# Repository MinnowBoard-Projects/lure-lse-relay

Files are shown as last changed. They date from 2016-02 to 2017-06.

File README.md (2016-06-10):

# lure-lse-relay  
"Relay Lure" for MinnowBoard MAX / Turbot compatible boards Low Speed Expansion (LSE) header  

Features
4-channel Relay Lure that can handle ~6A, 110VAC / ~4A, 30VDC per channel(Take appropriate precautions when handling this board).  
Screw in Block terminals with Normally Closed and Normally open connections(5mm Pitch).   
GPIOs are protected using Optocouplers.    
Experimental header to connect an HC-06 type Bluetooth module to a UART port, to enable the control of the MinnowBoard with another Bluetooth enabled devices. 

---------------------------------------------

"Big Relay Lure" for MinnowBoard MAX / Turbot compatible boards Low Speed Expansion (LSE) header 

Features
8-channel Relay Lure that can handle ~6A, 110VAC / ~4A, 30VDC per channel(Take appropriate precautions when handling this board).  
Screw in Block terminals with Normally Closed and Normally open connections(9.52mm Pitch).   
GPIOs are protected using Optocouplers. 
1-Wire devices hub, devices can be hooked up via RJ11 connectors and/or screw in block terminals.
The "Big Relay Lure" is an external Lure with 4 holes(2.5mm diameter) for standoffs, connects to the MinnowBoard via a Ribbon Cable.  

Both Designs made in Diptrace 3.0

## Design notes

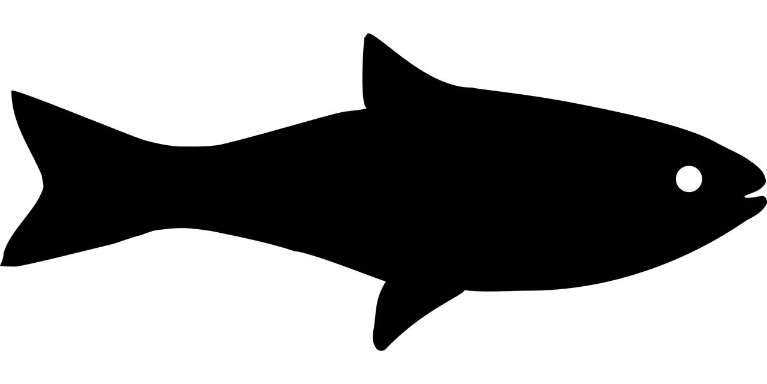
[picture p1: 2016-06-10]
Big Relay Board/Design Files/fish-1294822_1280.tiff

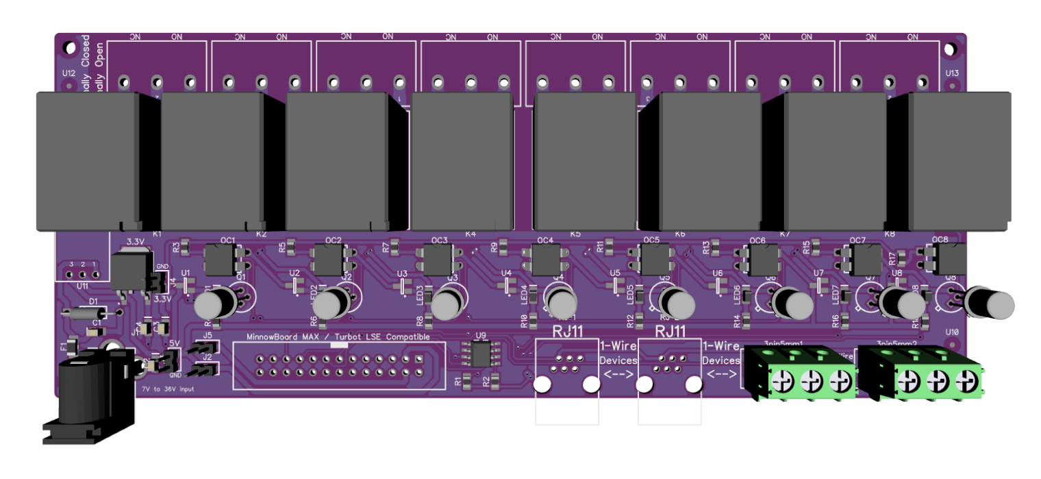
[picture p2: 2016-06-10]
Big Relay Board/Big Relay Lure front.png

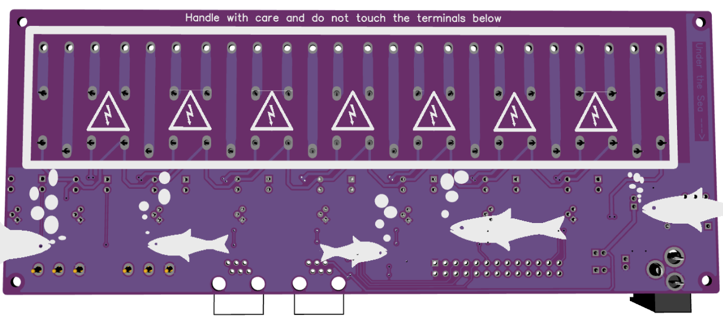
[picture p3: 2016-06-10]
Big Relay Board/Big Relay Lure back.png

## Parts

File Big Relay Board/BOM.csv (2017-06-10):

RefDes | Value | Name | Pattern | Manufacturer | Quantity | Datasheet
3.3V | 3.3V | BA033CC0FP-E2 | TO252-3(4)/10x6.6x2.28 | ROHM | 1
3pin5mm1 | BT1 | 1935174 | 3pin5mm | Phoenix Contact | 1
3pin5mm2 | BT2 | 1935174 | 3pin5mm | Phoenix Contact | 1
3pin6.35mm1 |  | 1714968 | 3pin6.35mm | Phoenix Contact | 1
3pin6.35mm2 |  | 1714968 | 3pin6.35mm | Phoenix Contact | 1
3pin6.35mm3 |  | 1714968 | 3pin6.35mm | Phoenix Contact | 1
3pin6.35mm4 |  | 1714968 | 3pin6.35mm | Phoenix Contact | 1
3pin6.35mm5 |  | 1714968 | 3pin6.35mm | Phoenix Contact | 1
3pin6.35mm6 |  | 1714968 | 3pin6.35mm | Phoenix Contact | 1
3pin6.35mm7 |  | 1714968 | 3pin6.35mm | Phoenix Contact | 1
3pin6.35mm8 |  | 1714968 | 3pin6.35mm | Phoenix Contact | 1
F1 |  | FUSE F1206A2R00FWTR\500 | RES_1206 | AVX | 1
J1 |  | PJ-002AH | PJ-002A | CUI | 1
J2 |  | 87758-02 | HDR-2x1T/2x2/2x4 | Molex | 1
J3 |  | 87758-02 | HDR-2x1T/2x2/2x4 | Molex | 1
J4 |  | 87758-02 | HDR-2x1T/2x2/2x4 | Molex | 1
J5 |  | 87758-02 | HDR-2x1T/2x2/2x4 | Molex | 1
K1 |  | G5LE-14-DC5 | G5LE | Omron | 1
K2 |  | G5LE-14-DC5 | G5LE | Omron | 1
K3 |  | G5LE-14-DC5 | G5LE | Omron | 1
K4 |  | G5LE-14-DC5 | G5LE | Omron | 1
K5 |  | G5LE-14-DC5 | G5LE | Omron | 1
K6 |  | G5LE-14-DC5 | G5LE | Omron | 1
K7 |  | G5LE-14-DC5 | G5LE | Omron | 1
K8 |  | G5LE-14-DC5 | G5LE | Omron | 1
OC1 |  | VO617A | DIP-4 | Vishay Semiconductors | 1 | http://www.vishay.com/doc?83666
OC2 |  | VO617A | DIP-4 | Vishay Semiconductors | 1 | http://www.vishay.com/doc?83666
OC3 |  | VO617A | DIP-4 | Vishay Semiconductors | 1 | http://www.vishay.com/doc?83666
OC4 |  | VO617A | DIP-4 | Vishay Semiconductors | 1 | http://www.vishay.com/doc?83666
OC5 |  | VO617A | DIP-4 | Vishay Semiconductors | 1 | http://www.vishay.com/doc?83666
OC6 |  | VO617A | DIP-4 | Vishay Semiconductors | 1 | http://www.vishay.com/doc?83666
OC7 |  | VO617A | DIP-4 | Vishay Semiconductors | 1 | http://www.vishay.com/doc?83666
OC8 |  | VO617A | DIP-4 | Vishay Semiconductors | 1 | http://www.vishay.com/doc?83666
RJ-1 |  | RJE01-660-01 | RJE01-660-01 | Amphenol | 1
RJ-2 |  | RJE01-660-01 | RJE01-660-01 | Amphenol | 1
ShroudedHeader |  | 61202621621 | Copy_of_shroudedheader26 | Wurth Electronics | 1
U1 |  | MMBD4148 | MMBD4148 | Fairchild | 1
U2 |  | MMBD4148 | MMBD4148 | Fairchild | 1
U3 |  | MMBD4148 | MMBD4148 | Fairchild | 1
U4 |  | MMBD4148 | MMBD4148 | Fairchild | 1
U5 |  | MMBD4148 | MMBD4148 | Fairchild | 1
U6 |  | MMBD4148 | MMBD4148 | Fairchild | 1
U7 |  | MMBD4148 | MMBD4148 | Fairchild | 1
U8 |  | MMBD4148 | MMBD4148 | Fairchild | 1
U9 |  | DS2482S-100 | SOIC-8/150mil | Maxim | 1 | http://datasheets.maxim-ic.com/en/ds/DS2482-100.pdf
U11 |  | OKI-78SR-5/1.5-W36H-C | OKI-78SR-5/1.5-W36H-C | Murata | 1
C1 | 4.7uF | CAP_0805 | CAP_0805 |  | 1
C2 | 4.7uF | CAP_0805 | CAP_0805 |  | 1
C3 | 0.1uF | CAP_0805 | CAP_0805 |  | 1
C4 | 4.7uF | CAP_0805 | CAP_0805 |  | 1
D1 | 1N4001 | DIODE | DO-35 |  | 1
LED1 |  | DIODE_0805 | DIO_0805 |  | 1
LED2 |  | DIODE_0805 | DIO_0805 |  | 1
LED3 |  | DIODE_0805 | DIO_0805 |  | 1
LED4 |  | DIODE_0805 | DIO_0805 |  | 1
LED5 |  | DIODE_0805 | DIO_0805 |  | 1
LED6 |  | DIODE_0805 | DIO_0805 |  | 1
LED7 |  | DIODE_0805 | DIO_0805 |  | 1
LED8 |  | DIODE_0805 | DIO_0805 |  | 1
Q1 |  | 2N2222 | TO-18 |  | 1
Q2 |  | 2N2222 | TO-18 |  | 1
Q3 |  | 2N2222 | TO-18 |  | 1
Q4 |  | 2N2222 | TO-18 |  | 1
Q5 |  | 2N2222 | TO-18 |  | 1
Q6 |  | 2N2222 | TO-18 |  | 1
Q7 |  | 2N2222 | TO-18 |  | 1
Q8 |  | 2N2222 | TO-18 |  | 1
R1 | Rup | RES_0805 | RES_0805 |  | 1
R2 | Rup | RES_0805 | RES_0805 |  | 1
R3 | 390 | RES_0805 | RES_0805 |  | 1
R4 | 180 | RES_0805 | RES_0805 |  | 1
R5 | 390 | RES_0805 | RES_0805 |  | 1
R6 | 180 | RES_0805 | RES_0805 |  | 1
R7 | 390 | RES_0805 | RES_0805 |  | 1
R8 | 180 | RES_0805 | RES_0805 |  | 1
R9 | 390 | RES_0805 | RES_0805 |  | 1
R10 | 180 | RES_0805 | RES_0805 |  | 1
R11 | 390 | RES_0805 | RES_0805 |  | 1
R12 | 180 | RES_0805 | RES_0805 |  | 1
R13 | 390 | RES_0805 | RES_0805 |  | 1
R14 | 180 | RES_0805 | RES_0805 |  | 1
R15 | 390 | RES_0805 | RES_0805 |  | 1
R16 | 180 | RES_0805 | RES_0805 |  | 1
R17 | 390 | RES_0805 | RES_0805 |  | 1
R18 | 180 | RES_0805 | RES_0805 |  | 1

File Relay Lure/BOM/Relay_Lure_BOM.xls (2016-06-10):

MinnowBoard MAX/Turbot Relay Lure
Mouser # | Mfr. # | Manufacturer | Desc. | RoHS | Lifecycle | Customer Part # | Order Qty. | Price (USD) | Ext.: (USD) | Direct Link
651-1935174 | 1935174 | Phoenix Contact | Fixed Terminal Blocks PT 1.5/3-5.0-H | RoHS Compliant |  |  | 4 | $0.52 | $2.08 | http://www.mouser.com/Search/ProductDetail.aspx?R=1935174virtualkey65100000virtualkey651-1935174
653-G5LE-14-DC5 | G5LE-14-DC5 | Omron | General Purpose Relays Power PCB Relay SPDT Sealed 5VDC | RoHS Compliant |  |  | 4 | $1.35 | $5.40 | http://www.mouser.com/Search/ProductDetail.aspx
610-2N2222 | 2N2222 | Central Semiconductor | Bipolar Transistors - BJT NPN Silicon | RoHS Compliant |  |  | 4 | $1.79 | $7.16 | http://www.mouser.com/Search/ProductDetail.aspx?R=2N2222virtualkey61000000virtualkey610-2N2222
855-M20-7831346 | M20-7831346 | Harwin | Headers & Wire Housings 13+13 DIL VERTICAL SOCKET TIN | RoHS Compliant |  |  | 1 | $2.36 | $2.36 | http://www.mouser.com/Search/ProductDetail.aspx
512-MMBD4148 | MMBD4148 | Fairchild Semiconductor | Diodes - General Purpose, Power, Switching High Cond Ult Fst Di | RoHS Compliant |  |  | 4 | $0.17 | $0.68 | http://www.mouser.com/Search/ProductDetail.aspx?R=MMBD4148virtualkey51210000virtualkey512-MMBD4148
652-CR0805JW-391ELF | CR0805-JW-391ELF | Bourns | Thick Film Resistors - SMD 390ohm 5% | RoHS Compliant By Exemption |  |  | 4 | $0.10 | $0.40 | http://www.mouser.com/Search/ProductDetail.aspx
78-VO617A | VO617A | Vishay | Transistor Output Optocouplers Phototransistor Out CTR 50-600% | RoHS Compliant |  |  | 4 | $0.60 | $2.40 | http://www.mouser.com/Search/ProductDetail.aspx?R=VO617Avirtualkey61370000virtualkey78-VO617A
667-ERJ-6GEYJ181V | ERJ-6GEYJ181V | Panasonic | Thick Film Resistors - SMD 0805 180ohms 5% Tol | RoHS Compliant By Exemption |  |  | 4 | $0.09 | $0.36 | http://www.mouser.com/Search/ProductDetail.aspx
696-SML-LXT0805IW | SML-LXT0805IW-TR | Lumex | Standard LEDs - SMD 0805 Thin PCB Red | RoHS Compliant |  |  | 4 | $0.35 | $1.40 | http://www.mouser.com/Search/ProductDetail.aspx

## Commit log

2016-02-20 Update README.md
    Relay Lure Features
2016-02-20 Update README.md
    Ampere handling in when using DC voltages, and message to take appropriate precautions when handling this board.
2016-02-27 Update to Rev 1.01
    Rev 1.01 includes minor fixes in the PCB layout from which new Gerber
    files were generated to reflect this changes.
    [BoardOutline.gbr, Bottom.gbr, BottomDimension.gbr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]
2016-03-10 Part rename
    Renamed the header part to “MAX / Turbot Compatible LSE” to make it
    easier to read and to show its compatibility between the MinnowBoard
    MAX and MinnowBoard Turbot. Design files were updated to make use of
    the new library with the renamed parts, Schematic.pdf and Gerber files
    updated as well.
    [BoardOutline.gbr, Bottom.gbr, BottomDimension.gbr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]
2016-03-31 Schematic clean-up
    Schematic was given a little clean-up, parts numbers, Manufacturer and
    link to Data sheet was added for multiple components. Still need to
    clean-up some more.
2016-04-01 Schematic clean up and .pdf refresh
    Schematic design file was cleaned, added parts numbers, manufacturer
    and link to data sheet to most parts and now show parts number on the
    schematic. Schematic in PDF was refreshed to show the changes.
2016-04-02 Add direct links to BOM
    Add direct links to Mouser in the BOM file, in order to make purchasing
    parts easier.
    [Relay_Lure_BOM.xls]
2016-04-02 Schematic refresh
    Schematic refresh, printed to A4 size.
2016-04-11 Added dots as pin 1 identifier for the VO617A Optocouplers and added lettering on the bottom silk mentioning that this Lure is compatible with MinnowBoard MAX and Turbot.
    Gerber files were updated to reflect the changes.
    [Board.gbr, BoardOutline.gbr, Bottom.gbr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]
2016-04-21 Updated library to match pin numbering on MinnowBoard
    Updated library to match pin numbering on MinnowBoard MAX / Turbot
    boards, updated design files to use this updated library, schematic PDF
    and gerber files updated too.
    [Board.gbr, BoardOutline.gbr, Bottom.gbr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]
2016-06-10 Added Big Relay Lure
    Added the Big Relay Lure files.
    [BOM.csv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]
2016-06-10 Update
    Updated README.md with information of the recently added Big Relay Lure.
2016-06-10 Update
    Added preview renders of the Big Relay Lure
2017-06-10 Block terminal fix
    Fixed wrong description of relay block terminal. Footprint is actually
    6.35mm in pitch instead of 9.52mm. Updated Schematic file, PDF
    schematic and BOM.
    [BOM.csv]
